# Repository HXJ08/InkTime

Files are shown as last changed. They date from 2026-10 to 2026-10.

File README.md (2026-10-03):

# InkTime

A 7.3" four-colour e-ink photo frame that shows a "today in history" photo every
morning. An ESP32-S3 wakes on a timer, pulls a pre-rendered 480x800 `.bin` frame
off a small HTTP host, paints it on a GDEM075F52 panel, overlays the live battery
level, and goes back to deep sleep.

The photos come from a self-hosted Immich library. A scoring pass picks the
photos that are actually worth showing, and a renderer composites the things you
actually want to see printed next to them: camera model, lens, exposure settings,
date and location.

```
Immich  ──►  analyze_photos.py  ──►  photos.db  ──►  render_daily_photo.py
(server)      VLM scoring pass       (SQLite)         compositing + dithering
                                                             │
                                                    photo_0..N.bin + previews
                                                             │
                                                             ▼
                                                 HTTP host ──► ESP32-S3 frame
```

## Gallery

**PCB** — ESP32-S3-InkDisplay v1.0, 100×33 mm, 2-layer. Red = top copper, blue = bottom, purple = vias.

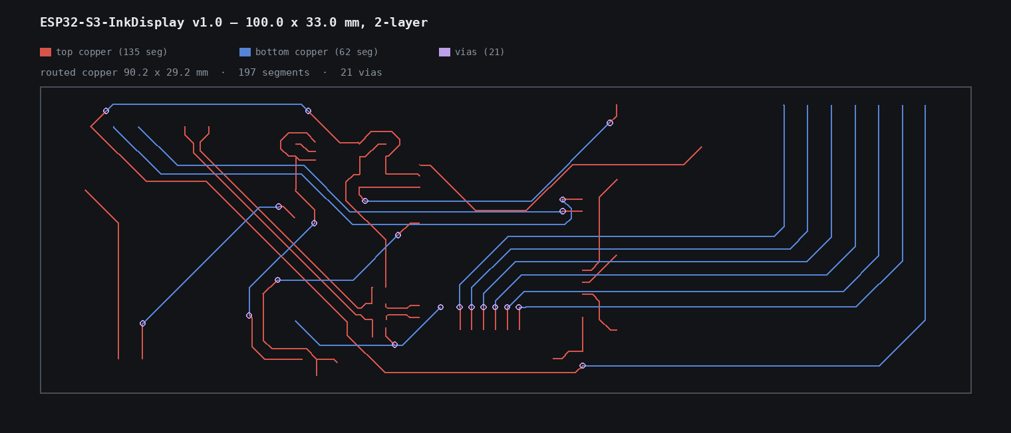
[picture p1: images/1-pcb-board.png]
PCB layout


**Rendered frame** — 480×800, 4-colour e-ink. Photo on top, specs + battery icon + date/location below.

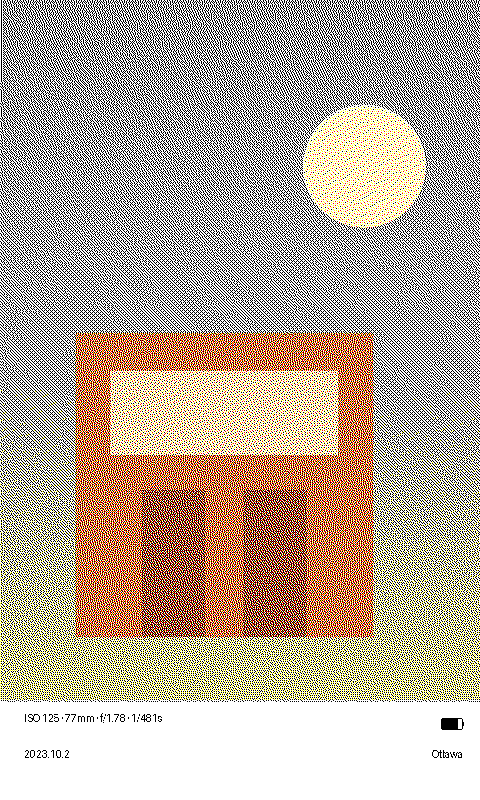
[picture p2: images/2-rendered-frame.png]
Rendered e-ink frame


**Repo** — 17 files, 5 commits on `main`.

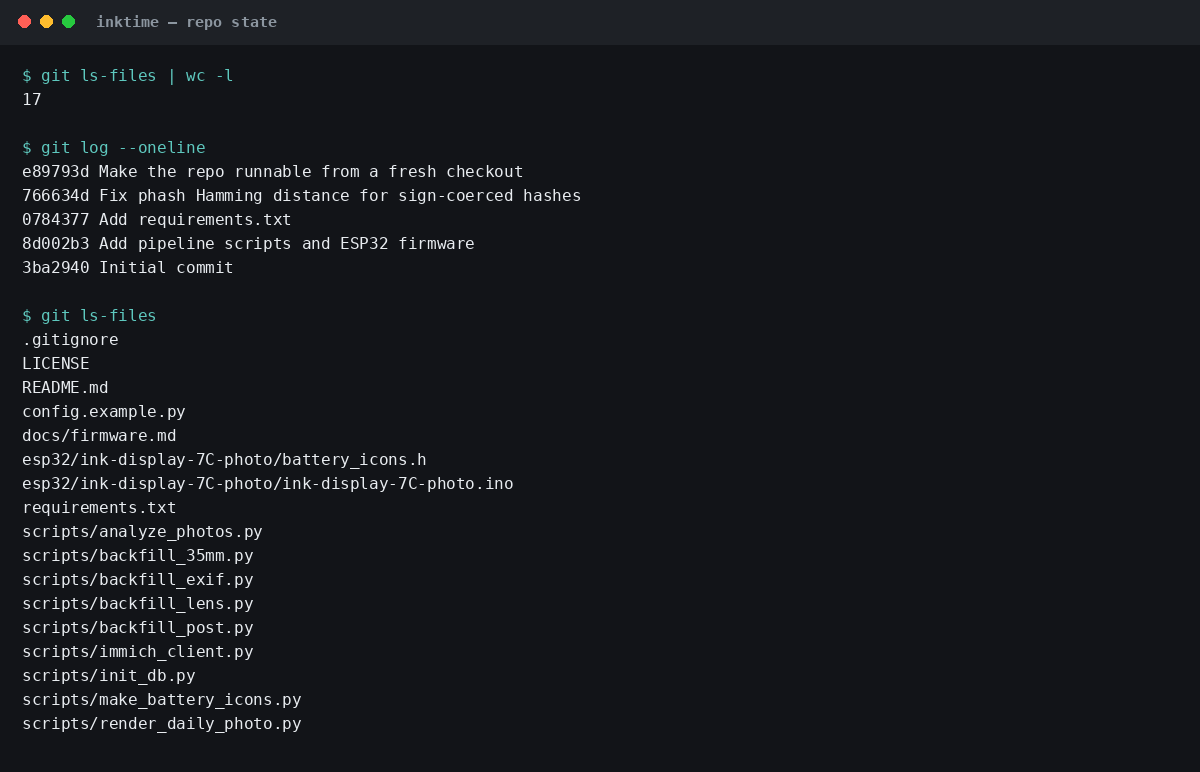
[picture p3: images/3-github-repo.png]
GitHub repo


## What is here

| Path | Role |
|---|---|
| `scripts/analyze_photos.py` | Pulls assets from Immich, scores them with a vision model, extracts EXIF, writes `photos.db` |
| `scripts/immich_client.py` | Immich REST client (ping, asset info, thumbnails, cache sync) |
| `scripts/render_daily_photo.py` | Selects today's photos, composites the info panel, dithers to 4 colours, writes `.bin` + previews |
| `scripts/init_db.py` | Creates a fresh `photos.db` with the full schema |
| `scripts/make_battery_icons.py` | Regenerates `battery_icons.h` (11 icons, 0-100%) |
| `scripts/backfill_*.py` | One-off repair passes over an existing database |
| `esp32/ink-display-7C-photo/` | Device firmware. Captive-portal Wi-Fi setup, download, battery overlay, deep sleep |
| `config.example.py` | Template for the untracked `config.py`; copy it to the repo root and edit |
| `docs/firmware.md` | Pinout, battery divider, `arduino-cli` build flags, calibration procedure |
| `hardware/` | PCB source (`.epro2`) and `bom.csv` — see `hardware/README.md` |

## The frame

`esp32/ink-display-7C-photo/` is one sketch plus one generated header.

- Panel: GDEM075F52, 480x800, four colours (black / white / red / yellow).
- Board: ESP32-S3 N8R8 (8 MB OPI PSRAM, 16 MB flash).
- `battery_icons.h` holds eleven 24x24 icons, 1 byte per pixel, palette `0=black 1=white 2=red 3=yellow`.
  Index 1 is transparent: the firmware paints white underneath and skips it.
- Battery is read on a 1S LiPo through a 100k/100k divider into an ADC pin, with a
  calibration factor and an 11-step voltage table in the sketch.
- `DAILY_PHOTO_PATH_PREFIX` in the sketch **must match** the renderer's output
  directory on the server. It ships as `CHANGEME_32_HEX_DOWNLOAD_KEY`; change it
  before flashing, otherwise the URL your frame requests is guessable by anyone
  who can reach the host.

Build flags matter. `build.psram=opi` is not optional: without it the framebuffer
allocation fails and init spins. Full command and the calibration walkthrough are
in `docs/firmware.md`.

## Server setup

Requires Python 3.10+, `Pillow`, `pillow-heif`, `requests`, and `exiftool` on
`PATH` (used for GPS/EXIF on originals; the pipeline degrades gracefully without it).

```sh
python -m venv venv && . venv/bin/activate
pip install -r requirements.txt
cp config.example.py config.py   # then edit it
```

`config.py` is read by every script and is **not** tracked. `config.example.py`
documents every key; the ones you cannot skip:

- `IMMICH_URL`, `IMMICH_API_KEY` - your Immich server. The key needs
  `asset.read`, `asset.view`, `asset.download` and `asset.update`.
  `asset.view` is a separate scope; without it thumbnails 403 even for the owner.
- `DB_PATH` - SQLite file. Everything else hangs off it.
- `BIN_OUTPUT_DIR` - where `.bin` frames land. Serve this over HTTP at the path
  prefix compiled into the firmware.
- `API_CHANNELS` - vision-model endpoints. Each entry is
  `{"api_url": ..., "model": ..., "api_key": "env:VAR_NAME"}`. Listing more than
  one makes the pass fail over on 429 instead of stalling.
- `WORLD_CITIES_CSV` - a GeoNames-style CSV with `lat,lon,name_en,name_zh`
  columns, used for reverse geocoding. Not shipped: it is a few MB of upstream
  data. Without it the location line renders empty rather than wrong.

Then:

```sh
python scripts/init_db.py                 # once: create the database schema
python scripts/analyze_photos.py -j 1     # score + ingest. -j 1: SQLite deadlocks higher
python scripts/render_daily_photo.py      # today's frames -> BIN_OUTPUT_DIR
```

Both are designed to run from cron or a container scheduler. The analyzer is
idempotent per asset; the renderer marks what it used so the next run picks
different photos.

## Database

One SQLite file, one main table. `photo_scores` is keyed on `path`, with
`immich_asset_id` as the join key back to Immich, plus the EXIF columns the
renderer reads (`exif_datetime`, `exif_make`, `exif_model`, `exif_iso`,
`exif_exposure_time`, `exif_f_number`, `exif_focal_length`, `exif_lens`,
`exif_focal_35mm`, `exif_file_size`, `exif_gps_*`, `exif_city`), the scoring
columns (`memory_score`, `beauty_score`, `reason`), and bookkeeping (`phash`,
`used_at`, `people_json`).

Two notes for anyone adapting this:

- `ensure_table()` creates `photo_scores` and `face_allowlist`, and adds columns
  individually for forward migration. `photo_blacklist` and the newer EXIF
  columns (`exif_focal_35mm`, `exif_lens`, `exif_file_size`, `album`) were added
  by the backfill scripts on the original deployment and are not created by
  `ensure_table()` — so run `scripts/init_db.py` once against a fresh database
  (it is idempotent) or the renderer's LEFT JOIN fails on first run.
- `phash` is stored as an integer in a signed column. Perceptual hashes use the
  full 64-bit range and are compared with Hamming distance after masking; if you
  rewrite the dedupe path, keep the masking.

## Selection

A photo is eligible when it has a parseable EXIF blob, scores above
`MEMORY_THRESHOLD`, is not blacklisted, and was not used inside
`USED_COOLDOWN_DAYS`. Among the eligible set the renderer prefers the same
calendar day in past years; if nothing clears the bar it walks back a day at a
time, and finally falls back to the global maximum. `DAILY_PHOTO_QUANTITY`
frames are written per run and the frame picks one at random, so a day's frame is
not predictable from the last one.

Deduplication runs before scoring, not after: an 8x8 difference hash with a
strict distance for near-identical frames, plus a wider distance inside a short
time window to catch bursts. It costs a model call to score a photo, so throwing
out the near-duplicates first is the cheap order.

## Attribution

The 4-colour dithering and the info-panel layout follow the conventions of
Apple Photos' detail panel (camera, lens, exposure, date, place). Focal length is
shown as the **35mm equivalent**, read from EXIF tag `0xA405`, because that is the
number people recognise; the physical value is meaningless for phone photos.
Previews render a copy of the battery icon so the PNG matches the frame; the
`.bin` deliberately does not contain it, because the frame draws the live level.

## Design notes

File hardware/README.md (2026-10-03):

# Hardware

PCB source and bill of materials for the InkTime frame.

| File | What it is |
|---|---|
| `ESP32-S3-InkDisplay-v1.0.epro2` | EasyEDA Pro project (opens in EasyEDA Pro) |
| `project2.json` | Project manifest, extracted from the `.epro2` |
| `bom.csv` | Bill of materials, exported from EasyEDA — 17 line items, 24 components |

## Board

**ESP32-S3-InkDisplay v1.0** — 100.0 × 33.0 mm, 2-layer.

Originally an open-source design by `Donald` (the silkscreen credits him);
modified by HXJ08. The `.epro2` dated 2026-10-02 is the modified revision.

**Power path:**

```
LiPo ──► TP4056 (charge) ──► VBAT ──► MIC5219-3.3 LDO ──► 3V3 ──► ESP32-S3
                                    └──► 100k/100k divider ──► ADC (battery sense)
```

**Display:** 8-pin SPI header (BUSY / CS / DC / RST / DIN / SCK / 3V3 / GND) to the
GDEM075F52 panel.

**USB:** D+/D− routed as a declared differential pair (DP1/DP2).

## BOM

Sourced from EasyEDA's own export (`BOM_V1_PCB1_2026-10-03.xlsx`), so the LCSC
supplier part numbers are included and the values are authoritative.

| Designators | Qty | Value | Manufacturer Part | LCSC |
|---|---|---|---|---|
| C1 | 1 | 4.7 µF | `CL10A475KO8NNNC` | C19666 |
| C2 | 1 | 10 µF | `CL10A106KP8NNNC` | C19702 |
| C3 | 1 | 100 nF | `CL10B104KB8NNNC` | C1591 |
| C4 | 1 | 1 µF | `CL10A105KB8NNNC` | C15849 |
| C5, C6 | 2 | 47 pF | `CL10C470JB8NNNC` | C1671 |
| C7 | 1 | 100 nF | — | — |
| R1, R4 | 2 | 10 kΩ | `RC1608F103CS` | C17441167 |
| R2, R3 | 2 | 22 Ω | `0603WAF220JT5E` | C23345 |
| R5, R6 | 2 | 100 kΩ | — | — |
| SW1-SW4 | 4 | — | `KH-6X6X5H-STM` | C2837531 |
| H1 | 1 | — | `PZ254V-11-04P` | C2691448 |
| H2 | 1 | — | `PZ254V-11-02P` | C492401 |
| H3 | 1 | — | `PZ254V-11-01P` | C492400 |
| H4 | 1 | — | `HC-PZ254-11.5L-1x8PZ` | C27985192 |
| U1 | 1 | — | `ESP32-S3-WROOM-1-N8R8` | C2913201 |
| U2 | 1 | — | `MIC5219-3.3YM5-TR` | C29613 |
| U3 | 1 | — | `TP4056` | — |

**24 components total.** C7, R5/R6 and U3 have values but no supplier part number
recorded — they are generic and need picking at order time.

## Notes before ordering

- **Two footprints are marked `DNI`** on the silkscreen. If they are deliberate, the
  assembler must be told to skip them.
- **No DRC result is stored in the project file.** The design rules are present
  (0.127 mm min track, 0.15 mm gap, 0.30 mm board-edge clearance) but a clean pass is
  not asserted — re-run DRC in EasyEDA first.
- **`bom.csv` is EasyEDA's export, not a derivation.** An earlier version of this file
  was reconstructed by parsing the PCB geometry and got three parts wrong: C2 as 4.7 µF
  instead of 10 µF, C7 as blank instead of 100 nF, and R5/R6 as 10 kΩ instead of 100 kΩ.
  The schematic knows values the PCB file does not, which is why the export supersedes it.

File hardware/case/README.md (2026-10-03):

# Case

3D-printed enclosure for the InkTime frame.

| File | What it is |
|---|---|
| `Inktime.stl` | Mesh export, ready to slice |
| `Inktime.f3d` | Autodesk Fusion 360 source document |
| `case_features.png` | Rendered features sheet (iso, cutaway, two sections) |

## Dimensions

**152.5 × 202.5 × 17.0 mm.** The tall dimension is the panel length: a 7.3"
display is 163 mm on the diagonal, so the case carries it with a margin for the
bezel lip.

**2,838 triangles, watertight** (0 open boundary edges), enclosing **131.9 cm³**
of material. Roughly 165 g of PLA at 1.24 g/cm³ before slicing adds walls and infill.

## Structure

The part is an **open tray**, not a closed box:

- **3 mm base** at z ≈ 3, with the outer floor at z ≈ 0.2
- **End walls** rising to z ≈ 10.4
- **Internal ribs and bosses** along the length, at a repeating pitch — visible in
  the X-section, these are the standoffs that hold the PCB and stop the base flexing
- **Bezel lip** at z = 14.2 → 17.2, the raised rim that frames the panel
- Two small slots in the top face near the midpoint

Height bands in the model: 3.2 mm (base top), 6.0 mm, 10.4 mm (wall top),
13.2 mm, 14.2 mm (bezel start), 17.2 mm (bezel top).

## Source

The Fusion document carries a `Toolpath` asset, so there is a CAM setup saved
alongside the model. `Inktime.f3d` is the authoritative source — edit that and
re-export the STL rather than editing the mesh.

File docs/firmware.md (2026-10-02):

# InkTime 7C-photo 固件构建

适用于 **ESP32-S3 N8R8 + GDEM075F52 (480x800 4 色屏)** 墨水相框。

## 引脚对照

| 信号 | GPIO | 备注 |
|---|---|---|
| EPD BUSY | 9 |  |
| EPD RST  | 12 |  |
| EPD DC | 11 |  |
| EPD CS | 10 |  |
| EPD SCK  | 14 |  |
| EPD MOSI | 13 |  |
| BAT ADC  | 6  | 1S LiPo + 100k+100k 1:2 分压 |
| FACTORY RESET | 38 | 上电低电平触发 |
| LED | 2 | LED_BUILTIN |

## 电池分压电路

```
B+ ──┬── 100k ──┬── GPIO6
B- ──┘          │
                ├── 100k ── GND
                │
ESP32 GND ──────┘
```

## arduino-cli 构建命令

```bash
arduino-cli compile \
  --fqbn esp32:esp32:esp32s3 \
  --build-property "build.psram=opi" \
  --build-property "build.flash_size=16MB" \
  --build-property "build.partitions=min_spiffs" \
  --build-property "build.board=ESP32-S3-DevKitC-1" \
  --build-property "build.variant=esp32s3" \
  -u \
  esp32/ink-display-7C-photo
```

> ⚠️ `build.psram=opi` 必填，否则 framebuffer 分配失败 / init 死循环。
> ⚠️ N8R8 = 8MB OPI PSRAM，必须显式声明。
> ⚠️ `min_spiffs` 选这个分区方案以腾出更多 app 空间。

## GxEPD2 库

库版本 ≥ 1.5.x（需要 `GxEPD2_750c_GDEM075F52` 驱动 + `GxEPD2_4C` 模板）。

Arduino IDE 库管理器搜 "GxEPD2" 装最新即可。

## 画面布局（Apple Photos 风格信息面板）

渲染器（`render_daily_photo.py`）在照片底部 140px 区域画 5 行信息：

```
[相机型号(粗体)]                    [电池图标(ESP32 叠加)]
[镜头名称]
[分辨率 · 文件大小]
[ISO · 焦距 · 光圈 · 快门]
[日期]                    [地点]
```

- 电池图标位置：`battery_icons.h` 里 `BATTERY_ICON_X/Y`（440, 676），
  ESP32 在下载 .bin 后把它叠加到 framebuffer，渲染器留出该区域。
- 文字区高度 `TEXT_AREA_HEIGHT = 140`（y=660..800），渲染器与固件必须保持同步。

## 电池阈值（LiPo 9060100 8000mAh 1S）

| 等级 | 电池端 mV | 备注 |
|---|---|---|
| 100% | ≥ 4125 | 4.125V |
| 90%  | ≥ 3950 | 3.95V |
| 80%  | ≥ 3850 | 3.85V |
| 70%  | ≥ 3780 | 3.78V |
| 60%  | ≥ 3720 | 3.72V |
| 50%  | ≥ 3660 | 3.66V |
| 40%  | ≥ 3600 | 3.60V |
| 30%  | ≥ 3550 | 3.55V |
| 20%  | ≥ 3450 | 3.45V |
| 10%  | ≥ 3300 | 3.30V |
| 0% | < 3300 | 3.00V 以下视为关机电压（代码里 3000mV 为下限） |

可在 `ink-display-7C-photo.ino` 顶部 `BATTERY_LEVEL_MV[]` 数组里按实际带载标定。

### 校准（解决 ADC 误差）

ADC eFuse 校准 + 电阻公差会让读出的电压有几 % 偏差。校准步骤：

1. 烧当前固件，串口 log 里看 `[BAT] adcMv=XXXX batMv=YYYY`（YYYY 是当前算出的电池电压）
2. 万用表量电池两端电压 V_actual
3. 算 `factor = V_actual / YYYY`
4. 改 `BATTERY_CALIBRATION_FACTOR` 常量，重刷

例：万用表 4.126V，串口 log 显示 `batMv=4050` → `factor = 4.126 / 4.050 = 1.019` → 改成 `1.019f`。

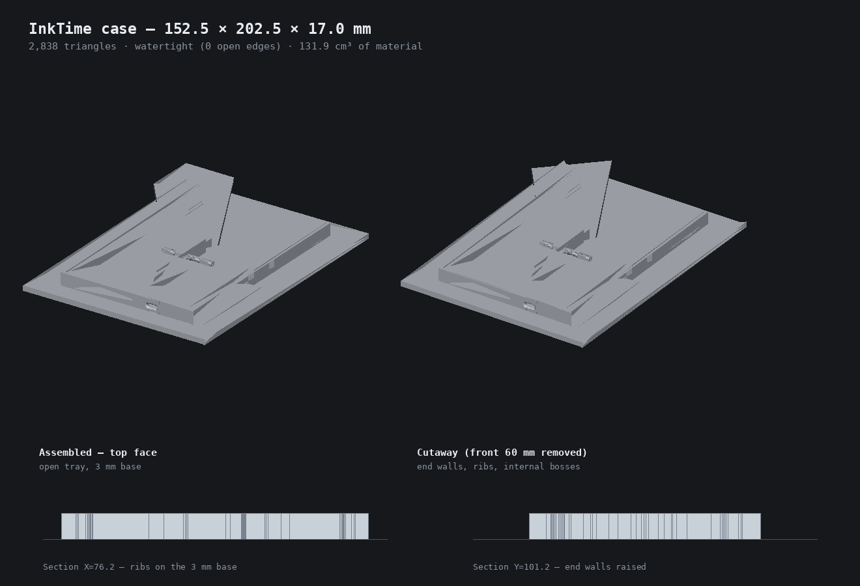
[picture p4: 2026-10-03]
hardware/case/case_features.png

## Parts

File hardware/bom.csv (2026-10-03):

Designator | Quantity | Value | Manufacturer Part | Manufacturer | Supplier Part | Supplier | Footprint
C1 | 1 | 4.7uF | CL10A475KO8NNNC | SAMSUNG(三星) | C19666 | LCSC | C0603
C2 | 1 | 10uF | CL10A106KP8NNNC | SAMSUNG(三星) | C19702 | LCSC | C0603
C3 | 1 | 100nF | CL10B104KB8NNNC | SAMSUNG(三星) | C1591 | LCSC | C0603
C4 | 1 | 1uF | CL10A105KB8NNNC | SAMSUNG(三星) | C15849 | LCSC | C0603
C5,C6 | 2 | 47pF | CL10C470JB8NNNC | SAMSUNG(三星) | C1671 | LCSC | C0603
C7 | 1 | 100nF |  |  |  |  | C0603
H1 | 1 | PZ254V-11-04P | PZ254V-11-04P | XFCN(兴飞) | C2691448 | LCSC | HDR-TH_4P-P2.54-V-M
H2 | 1 | PZ254V-11-02P | PZ254V-11-02P | XFCN(兴飞) | C492401 | LCSC | HDR-TH_2P-P2.54-V-M
H3 | 1 | PZ254V-11-01P | PZ254V-11-01P | XFCN(兴飞) | C492400 | LCSC | HDR-TH_1P-P2.54-V-M
H4 | 1 | HC-PZ254-11.5L-1x8PZ | HC-PZ254-11.5L-1x8PZ | HC(虹成电子) | C27985192 | LCSC | HDR-TH_8P-P2.54-V-M
R1,R4 | 2 | 10kΩ | RC1608F103CS | SAMSUNG(三星) | C17441167 | LCSC | R0603
R2,R3 | 2 | 22Ω | 0603WAF220JT5E | UNI-ROYAL(厚声) | C23345 | LCSC | R0603
R5,R6 | 2 | 100kΩ |  |  |  |  | R0603
SW1,SW2,SW3,SW4 | 4 | KH-6X6X5H-STM | KH-6X6X5H-STM | kinghelm(金航标) | C2837531 | LCSC | SW-SMD_4P-L6.0-W6.0-P4.50-LS9.0_H5.0
U1 | 1 | ESP32-S3-WROOM-1-N8R8 | ESP32-S3-WROOM-1-N8R8 | ESPRESSIF(乐鑫) | C2913201 | LCSC | WIRELM-SMD_ESP32-S3-WROOM-1
U2 | 1 | MIC5219-3.3YM5-TR | MIC5219-3.3YM5-TR | MICROCHIP(美国微芯) | C29613 | LCSC | SOT-23-5_L3.0-W1.7-P0.95-LS2.8-TL
U3 | 1 | TP4056 |  |  |  |  | PWRM-TH_TP4056

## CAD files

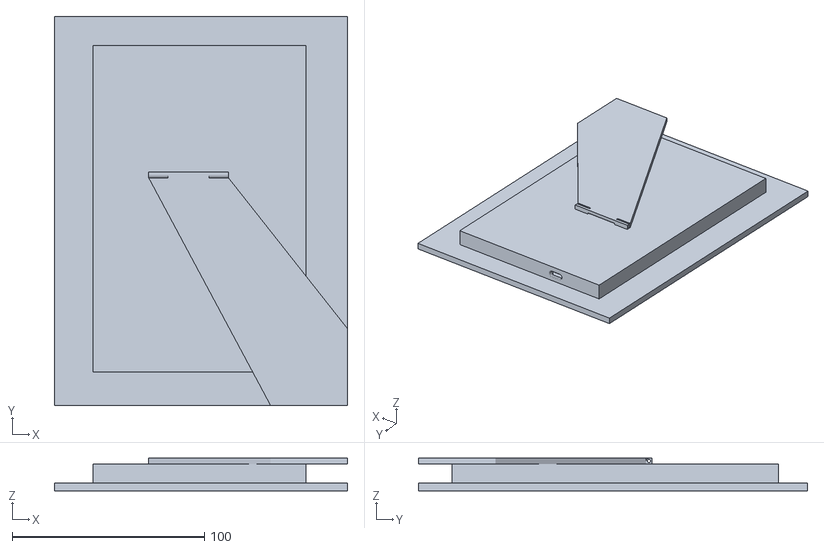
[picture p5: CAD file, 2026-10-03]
hardware/case/Inktime.stl
152.5 x 202.5 x 17.0

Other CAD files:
hardware/case/Inktime.f3d

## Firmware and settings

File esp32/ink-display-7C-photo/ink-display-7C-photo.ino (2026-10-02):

#include <WiFi.h>
#include <WebServer.h>
#include <HTTPClient.h>
#include <Preferences.h>
#include <SPI.h>
#include <time.h>
#include "esp_heap_caps.h"
#include "esp_system.h"
#include "esp_sleep.h"

#include <GxEPD2_4C.h>
#include <HardwareSerial.h>
#include "esp_wifi.h"
#include "esp_bt.h"

#include "driver/gpio.h"
#include "driver/rtc_io.h"

#include "battery_icons.h"

// =======================
//  调试开关（需要串口时改成 1）
// =======================
#define DEBUG_LOG 0

HardwareSerial DebugSerial(0);

#if DEBUG_LOG
  #define DBG_BEGIN()    DebugSerial.begin(115200)
  #define DBG_PRINT(x)   DebugSerial.print(x)
  #define DBG_PRINTLN(x) DebugSerial.println(x)
#else
  #define DBG_BEGIN()
  #define DBG_PRINT(x)
  #define DBG_PRINTLN(x)
#endif

#ifndef LED_BUILTIN
#define LED_BUILTIN 2
#endif

// =======================
//  恢复出厂设置：上电时按下 GPIO38 -> 清 NVS 中的 WiFi/配置，并进入 AP 配网
// =======================
#define PIN_FACTORY_RESET 38
#define FACTORY_RESET_ACTIVE_LOW 1
static const uint32_t FACTORY_RESET_SAMPLE_DELAY_MS = 5;

// =======================
//  AP 配置页保底：进入 AP 后 5 分钟没保存配置 -> 睡到“下一个刷新点”
// =======================
static const uint32_t AP_TIMEOUT_MS = 5UL * 60UL * 1000UL; // 5 分钟

// =======================
//  墨水屏参数 & 引脚
// =======================
// 逻辑分辨率：竖屏 480x800
static const int EPD_WIDTH  = 800;
static const int EPD_HEIGHT = 480;
static const int FB_WIDTH   = 480;
static const int FB_HEIGHT  = 800;

// SPI引脚 (重映射: BUSY=9, RST=12, DC=11, CS=10, SCK=14, MOSI=13)
#define PIN_EPD_BUSY 9
#define PIN_EPD_RST  12
#define PIN_EPD_DC   11
#define PIN_EPD_CS   10
#define PIN_EPD_SCLK 14
#define PIN_EPD_DIN  13

// =======================
//  电池电量检测 (1S LiPo 3.7V 8000mAh, 100k+100k 1:2 分压到 ADC)
// =======================
// 分压前电池电压: 4.20V (满) -> 3.00V (空)
// 分压后 ADC 端电压: 2.10V -> 1.50V
// ADC 引脚: GPIO6 (ADC1_CH5 on ESP32-S3, ADC2 在 WiFi 占用时不可用)
#define PIN_BATTERY_ADC   6
#define BATTERY_ADC_ATTEN ADC_11db          // ESP32-S3 上对应 0-3.3V 量程 (Arduino core 3.x 改名为 ADC_11db)
#define BATTERY_DIVIDER_RATIO 2.0f         // V_adc/V_bat = 100k/200k = 0.5 -> V_bat = V_adc * 2
#define BATTERY_ADC_SAMPLES 16

// 校准因子 — 补偿 ADC eFuse 误差 + 电阻公差
// 校准步骤:
//   1. 烧固件, 串口 log 看 [BAT] adcMv=XXXX (这是 ADC 引脚实测 mV, 已扣分压)
//   2. 用万用表实测电池两端 V_actual
//   3. factor = V_actual / (adcMv × 2.0)   ← 直接基于原始 adcMv 算, 不受上一次的 cal 影响
//   4. 改这个常量, 重刷
// 例: adcMv=2048, 万用表=4.126V → factor = 4.126 / (2048×2.0/1000) = 4.126 / 4.096 = 1.0073
#define BATTERY_CALIBRATION_FACTOR 1.0150f  // ← 改这个值校准

// LiPo 放电曲线 -> 11 段离散等级 (0,10,20,...,100)
// 阈值数组是分压前 (电池端) 电压 mV，从高到低排列
static const uint16_t BATTERY_LEVEL_MV[11] = {
  4125,  // 100% (>= 4.125V)
  3950,  //  90% (>= 3.95V)
  3850,  //  80% (>= 3.85V)
  3780,  //  70% (>= 3.78V)
  3720,  //  60% (>= 3.72V)
  3660,  //  50% (>= 3.66V)
  3600,  //  40% (>= 3.60V)
  3550,  //  30% (>= 3.55V)
  3450,  //  20% (>= 3.45V)
  3300,  //  10% (>= 3.30V)
  3000,  //   0% (<  3.30V; 3.00V 为截止/关机电压)
};
static const uint8_t  BATTERY_LEVEL_PCT[11] = { 100, 90, 80, 70, 60, 50, 40, 30, 20, 10, 0 };

// 屏幕: GDEM075F52 (480x800 4色 panel, GDEM 系列 50ms reset)
// 4 色 panel class + GDEM 驱动。如果换用其它屏幕，请自行修改此处
GxEPD2_4C<
  GxEPD2_750c_GDEM075F52,
  GxEPD2_750c_GDEM075F52::HEIGHT / 4
> display(
  GxEPD2_750c_GDEM075F52(
    PIN_EPD_CS,
    PIN_EPD_DC,
    PIN_EPD_RST,
    PIN_EPD_BUSY
  )
);

// =======================
//  静态每日相册 BIN 路径前缀，建议修改，防止隐私泄露。需同步修改 config.py 中的 DOWNLOAD_KEY。
// =======================
#define DAILY_PHOTO_PATH_PREFIX "/static/inktime/CHANGEME_32_HEX_DOWNLOAD_KEY/photo_"
#define DAILY_PHOTO_COUNT       10   // 0..9

// =======================
//  配置存储 / WiFi / WebServer
// =======================
Preferences prefs;
WebServer  server(80);

struct Config {
  String  wifi_ssid;
  String  wifi_pass;
  String  backend_hostport;
  int32_t tz_offset_hours;   // legacy: 静态时区偏移,只在 tz_label 为空时使用
  String  tz_label;          // 选自 TZ_TABLE[i].label,带 DST 规则
  uint8_t refresh_hour;
  bool    rotate180;
  bool    valid;
};

const char*  DEFAULT_HOSTPORT = "";
const int32_t DEFAULT_TZ      = 8;
const uint8_t DEFAULT_HOUR    = 8;

Config g_cfg;
uint8_t* framebuffer = nullptr;

// =======================
//  时区表 (北美优先,含 DST 规则)
//  偏移量:东正西负,以秒计(与 configTime 的 gmtOffset_sec 同向)
//  DST 规则:美加 2007 年后统一(3 月第 2 个周日 -> 11 月第 1 个周日)
//  没有 DST 的地区 hasDst=false, dstOffsetSec 等于 stdOffsetSec
// =======================
struct TzInfo {
  const char* iana;           // IANA 时区名(用于 IP 检测匹配)
  const char* label;          // 下拉框里显示的完整标签(也是 NVS 里存的 key)
  int         stdOffsetSec;   // 标准时间偏移 (UTC+0 为 0)
  int         dstOffsetSec;   // 夏令时偏移
  bool        hasDst;         // 是否观察 DST
  const char* posix;          // POSIX TZ 字符串(参考,运行时不用)
};
static const TzInfo TZ_TABLE[] = {
  // 美东
  {"America/Halifax",     "America/Halifax (AST/ADT, PEI/NS/NB)",   -14400, -10800, true,  "AST4ADT,M3.2.0,M11.1.0"},
  {"America/St_Johns",    "America/St_Johns (NST/NDT, NL)",         -12600,  -9000, true,  "NST3:30NDT,M3.2.0,M11.1.0"},
  {"America/New_York",    "America/New_York (EST/EDT)",             -18000, -14400, true,  "EST5EDT,M3.2.0,M11.1.0"},
  {"America/Toronto",     "America/Toronto (EST/EDT, ON)",          -18000, -14400, true,  "EST5EDT,M3.2.0,M11.1.0"},
  // 美中
  {"America/Chicago",     "America/Chicago (CST/CDT)",              -21600, -18000, true,  "CST6CDT,M3.2.0,M11.1.0"},
  {"America/Winnipeg",    "America/Winnipeg (CST/CDT, MB)",         -21600, -18000, true,  "CST6CDT,M3.2.0,M11.1.0"},
  // 美山
  {"America/Denver",      "America/Denver (MST/MDT)",               -25200, -21600, true,  "MST7MDT,M3.2.0,M11.1.0"},
  {"America/Phoenix",     "America/Phoenix (MST, no DST, AZ)",      -25200, -25200, false, "MST7"},
  // 美西
  {"America/Los_Angeles", "America/Los_Angeles (PST/PDT)",          -28800, -25200, true,  "PST8PDT,M3.2.0,M11.1.0"},
  {"America/Vancouver",   "America/Vancouver (PST/PDT, BC)",        -28800, -25200, true,  "PST8PDT,M3.2.0,M11.1.0"},
  // 北美其它
  {"America/Anchorage",   "America/Anchorage (AKST/AKDT)",          -32400, -28800, true,  "AKST9AKDT,M3.2.0,M11.1.0"},
  {"Pacific/Honolulu",    "Pacific/Honolulu (HST, no DST)",         -36000, -36000, false, "HST10"},
  // 兜底
  {"UTC",                 "UTC",                                         0,      0,  false, "UTC0"},
  {"Asia/Shanghai",       "Asia/Shanghai (CST, no DST, 中国)",       28800,  28800, false, "CST-8"},
};
static const size_t TZ_TABLE_LEN = sizeof(TZ_TABLE) / sizeof(TZ_TABLE[0]);

// 按 label 查 TzInfo(线性查表,只有十几条,够用)
static const TzInfo* lookupTz(const String &label) {
  if (label.isEmpty()) return nullptr;
  for (size_t i = 0; i < TZ_TABLE_LEN; ++i) {
    if (label.equals(TZ_TABLE[i].label)) return &TZ_TABLE[i];
  }
  return nullptr;
}

// 按 IANA 名查 TzInfo(用于 IP 检测回填)
static const TzInfo* lookupTzByIana(const String &iana) {
  if (iana.isEmpty()) return nullptr;
  for (size_t i = 0; i < TZ_TABLE_LEN; ++i) {
    if (iana.equals(TZ_TABLE[i].iana)) return &TZ_TABLE[i];
  }
  return nullptr;
}

// 北美 DST 判断:3 月第 2 个周日(含) -> 11 月第 1 个周日(不含)
// 精度到"天",2 AM 边界的 1 小时误差对每日 8 AM 唤醒画屏可忽略
static bool isNorthAmericaDST(time_t nowUtc) {
  if (nowUtc <= 0) return false;
  struct tm utc;
  gmtime_r(&nowUtc, &utc);
  int year = utc.tm_year + 1900;
  if (year < 2007) return false;  // 2007 年前规则不同,不考虑

  // 算 3 月第 2 个周日 和 11 月第 1 个 周日 的"年中第几天"
  auto dayOfYear = [](int y, int m, int d) {
    static const int cum[] = {0,31,59,90,120,151,181,212,243,273,304,334};
    int doy = cum[m-1] + d;
    if (m > 2 && ((y%4==0 && y%100!=0) || y%400==0)) doy++;
    return doy;
  };
  auto weekdayOn1st = [](int y, int m) {
    // Zeller-like: 求某月 1 日是星期几 (0=Sun..6=Sat)
    static const int t[] = {0,3,2,5,0,3,5,1,4,6,2,4};
    int yy = y - (m < 3);
    int w = (yy + yy/4 - yy/100 + yy/400 + t[m-1] + 1) % 7;
    return w;  // 0=Sun
  };
  int firstSunMar = (7 - weekdayOn1st(year, 3)) % 7 + 1;  // 1..7
  int firstSunNov = (7 - weekdayOn1st(year, 11)) % 7 + 1;
  int dstStart = dayOfYear(year, 3, firstSunMar + 7);  // 2nd Sunday of March
  int dstEnd   = dayOfYear(year, 11, firstSunNov);     // 1st Sunday of November

  int doy = dayOfYear(year, utc.tm_mon + 1, utc.tm_mday);
  return (doy >= dstStart) && (doy < dstEnd);
}

// 计算当前应使用的 UTC 偏移(秒,东正)
// 优先用 tz_label(DST 自动),否则用老字段 tz_offset_hours
static int computeUtcOffsetSec(const Config &cfg) {
  const TzInfo* tz = lookupTz(cfg.tz_label);
  if (tz) {
    if (!tz->hasDst) return tz->stdOffsetSec;
    time_t nowUtc = time(nullptr);
    return isNorthAmericaDST(nowUtc) ? tz->dstOffsetSec : tz->stdOffsetSec;
  }
  return (int)cfg.tz_offset_hours * 3600;
}

// 把当前时区应用到 lwIP/SNTP 层;setup() 早期 + 任何 getLocalTime 前都要调一次
static void applyTimezone(const Config &cfg) {
  int offsetSec = computeUtcOffsetSec(cfg);
  configTime(offsetSec, 0, "pool.ntp.org", "time.nist.gov", "ntp.aliyun.com");
#if DEBUG_LOG
  DBG_PRINT("[TIME] tz="); DBG_PRINT(cfg.tz_label.isEmpty() ? String("(legacy)") : cfg.tz_label);
  DBG_PRINT(" offsetSec="); DBG_PRINTLN(offsetSec);
#endif
}

static void releaseAllGpioHoldsAtBoot() {
  gpio_deep_sleep_hold_dis();
  for (int gpio = 0; gpio <= 48; ++gpio) {
    gpio_num_t gn = (gpio_num_t)gpio;
    if (!GPIO_IS_VALID_GPIO(gn)) continue;
    gpio_hold_dis(gn);
    if (rtc_gpio_is_valid_gpio(gn)) rtc_gpio_hold_dis(gn);
  }
}

static void clearConfigNVS() {
#if DEBUG_LOG
  DBG_PRINTLN("[NVS] clearConfigNVS()");
#endif
  prefs.begin("dashcfg", false);
  prefs.clear();
  prefs.end();
}

static bool isFactoryResetRequestedAtBoot() {
  pinMode(PIN_FACTORY_RESET, INPUT_PULLUP);
  delay(FACTORY_RESET_SAMPLE_DELAY_MS);
#if FACTORY_RESET_ACTIVE_LOW
  return (digitalRead(PIN_FACTORY_RESET) == LOW);
#else
  return (digitalRead(PIN_FACTORY_RESET) == HIGH);
#endif
}

static void saveLastTimeEpoch(time_t epoch) {
  prefs.begin("dashcfg", false);
  prefs.putULong("last_epoch", (uint32_t)epoch);
  prefs.end();
#if DEBUG_LOG
  DBG_PRINT("[TIME] save last_epoch="); DBG_PRINTLN((uint32_t)epoch);
#endif
}

static bool loadLastTimeEpoch(time_t &epochOut) {
  prefs.begin("dashcfg", true);
  uint32_t v = prefs.getULong("last_epoch", 0);
  prefs.end();
  if (v == 0) return false;
  epochOut = (time_t)v;
  return true;
}

static uint32_t minutesToNextRefreshFromLastEpoch(const Config &cfg) {
  time_t lastEpoch;
  if (!loadLastTimeEpoch(lastEpoch)) {
    return 1440;
  }

  struct tm t;
  localtime_r(&lastEpoch, &t);

  int curMinOfDay = t.tm_hour * 60 + t.tm_min;
  int targetMin   = (int)cfg.refresh_hour * 60;
  int deltaMin;

  if (curMinOfDay < targetMin) deltaMin = targetMin - curMinOfDay;
  else                         deltaMin = 24 * 60 - (curMinOfDay - targetMin);

  if (deltaMin < 1) deltaMin = 24 * 60;
  if (deltaMin > 1440) deltaMin = 1440;
  return (uint32_t)deltaMin;
}

// =======================
//  配置读写
// =======================
void loadConfig(Config &cfg) {
  prefs.begin("dashcfg", true); // read-only
  cfg.wifi_ssid        = prefs.getString("ssid", "");
  cfg.wifi_pass        = prefs.getString("pass", "");
  cfg.backend_hostport = prefs.getString("hostport", DEFAULT_HOSTPORT);
  cfg.tz_offset_hours  = prefs.getInt("tz", DEFAULT_TZ);
  cfg.tz_label         = prefs.getString("tz_label", "");
  cfg.refresh_hour     = (uint8_t)prefs.getUChar("hour", DEFAULT_HOUR);
  cfg.rotate180        = prefs.getBool("rot180", false);
  prefs.end();

  cfg.valid = (cfg.wifi_ssid.length() > 0);

#if DEBUG_LOG
  DBG_PRINTLN("---- loadConfig ----");
  DBG_PRINT("[CFG] ssid="); DBG_PRINTLN(cfg.wifi_ssid);
  DBG_PRINT("[CFG] hostport="); DBG_PRINTLN(cfg.backend_hostport);
  DBG_PRINT("[CFG] tz_offset_hours="); DBG_PRINTLN(cfg.tz_offset_hours);
  DBG_PRINT("[CFG] tz_label="); DBG_PRINTLN(cfg.tz_label);
  DBG_PRINT("[CFG] refresh_hour="); DBG_PRINTLN((int)cfg.refresh_hour);
  DBG_PRINT("[CFG] rotate180="); DBG_PRINTLN(cfg.rotate180 ? "true" : "false");
  DBG_PRINT("[CFG] valid="); DBG_PRINTLN(cfg.valid ? "true" : "false");
#endif
}

void saveConfig(const Config &cfg) {
  prefs.begin("dashcfg", false);
  prefs.putString("ssid", cfg.wifi_ssid);
  prefs.putString("pass", cfg.wifi_pass);
  prefs.putString("hostport", cfg.backend_hostport);
  prefs.putInt("tz", cfg.tz_offset_hours);
  prefs.putString("tz_label", cfg.tz_label);
  prefs.putUChar("hour", cfg.refresh_hour);
  prefs.putBool("rot180", cfg.rotate180);
  prefs.end();

#if DEBUG_LOG
  DBG_PRINTLN("[CFG] saved");
#endif
}

// =======================
//  HTML 工具
// =======================
String htmlEscape(const String &s) {
  String out;
  out.reserve(s.length());
  for (size_t i = 0; i < s.length(); ++i) {
    char c = s[i];
    if      (c == '&')  out += F("&amp;");
    else if (c == '<')  out += F("&lt;");
    else if (c == '>')  out += F("&gt;");
    else if (c == '"')  out += F("&quot;");
    else                out += c;
  }
  return out;
}

static void wifiHardResetForPortal() {
#if DEBUG_LOG
  DBG_PRINTLN("[WIFI] wifiHardResetForPortal()");
#endif
  WiFi.scanDelete();
  WiFi.disconnect(true, true);
  WiFi.mode(WIFI_OFF);
  delay(200);

  WiFi.mode(WIFI_AP_STA);

  WiFi.setSleep(false);
  esp_wifi_set_ps(WIFI_PS_NONE);

  WiFi.scanDelete();
  delay(50);
}

String buildConfigPage() {
  WiFi.scanDelete();
  delay(30);

  int n = WiFi.scanNetworks(/*async=*/false, /*hidden=*/true);

#if DEBUG_LOG
  DBG_PRINT("[CFG] scanNetworks n="); DBG_PRINTLN(n);
#endif

  String curSsid  = g_cfg.wifi_ssid;
  String host     = htmlEscape(g_cfg.backend_hostport);
  int32_t tz      = g_cfg.tz_offset_hours;
  if (tz < -12 || tz > 14) tz = DEFAULT_TZ;
  String curTzLbl = g_cfg.tz_label;
  uint8_t hour    = g_cfg.refresh_hour;
  if (hour > 23) hour = DEFAULT_HOUR;
  bool rot180     = g_cfg.rotate180;

  String html;
  html.reserve(8192);

  html += F("<!DOCTYPE html><html><head><meta charset='utf-8'>");
  html += F("<meta name='viewport' content='width=device-width,initial-scale=1'>");
  html += F("<title>InkTime 设置</title></head><body>");
  html += F("<h2>InkTime 设置</h2>");
  html += F("<form method='POST' action='/save'>");

  html += F("WiFi SSID:<br>");
  html += F("<select id='ssid_select' style='width: 288px;' onchange=\"document.getElementById('ssid_input').value=this.value;\">");
  html += F("<option value=''>（手动输入或选择）</option>");
  if (n > 0) {
    for (int i = 0; i < n; ++i) {
      String s = WiFi.SSID(i);
      if (s.length() == 0) continue;
      String esc = htmlEscape(s);
      html += F("<option value='");
      html += esc;
      html += F("'");
      if (s == curSsid) html += F(" selected");
      html += F(">");
      html += esc;
      html += F("</option>");
    }
  }
  html += F("</select><br>");
  html += F("<input id='ssid_input' name='ssid' style='width: 280px;' value='");
  html += htmlEscape(curSsid);
  html += F("'><br><br>");

  html += F("密码:<br><input name='pass' type='password' style='width: 280px;'><br><br>");

  html += F("服务器 (host:port):<br><input name='hostport' size='40' value='");
  html += host;
  html += F("'><br><br>");

  html += F("每日刷新时间（0-23 点整）：<br><select name='hour'>");
  for (int h = 0; h < 24; ++h) {
    html += "<option value='";
    html += String(h);
    html += "'";
    if (h == hour) html += " selected";
    html += ">";
    html += String(h);
    html += F(" 点</option>");
  }
  html += F("</select><br><br>");

  html += F("时区（含 DST 自动切换）:<br>");
  html += F("<select name='tz_label' id='tz_label' style='width: 360px;'>");
  html += F("<option value=''>(不选,用下方手动偏移量)</option>");
  for (size_t i = 0; i < TZ_TABLE_LEN; ++i) {
    String lbl = String(TZ_TABLE[i].label);
    String esc = htmlEscape(lbl);
    html += "<option value='";
    html += esc;
    html += "'";
    if (lbl == curTzLbl) html += F(" selected");
    html += ">";
    html += esc;
    html += F("</option>");
  }
  html += F("</select>");
  html += F(" <button type='button' onclick='detectTz()'>根据 IP 自动检测</button><br>");
  html += F("<span id='tz_status' style='color:#666;font-size:12px;'></span><br>");
  html += F("<script>");
  html += F("function detectTz(){");
  html += F("var s=document.getElementById('tz_status');");
  html += F("s.textContent='检测中…';");
  html += F("fetch('/detect-tz').then(function(r){return r.text();}).then(function(t){");
  html += F("if(t==='FAIL'||t===''){s.textContent='检测失败,请手动选';s.style.color='#c00';return;}");
  html += F("var sel=document.getElementById('tz_label');");
  html += F("var hit=false;");
  html += F("for(var i=0;i<sel.options.length;i++){");
  html += F("if(sel.options[i].value===t){sel.selectedIndex=i;hit=true;break;}");
  html += F("}");
  html += F("if(hit){s.textContent='已自动选择: '+t;s.style.color='#080';}");
  html += F("else{s.textContent='检测到 '+t+' 但不在列表,请手动选';s.style.color='#c00';}");
  html += F("});}");
  html += F("</script><br>");

  html += F("手动偏移量 (仅当上面未选时区时生效, UTC+?):<br>");
  html += F("<select name='tz'>");
  for (int t = -12; t <= 14; ++t) {
    html += "<option value='";
    html += String(t);
    html += "'";
    if (t == tz) html += " selected";
    html += ">";
    if (t >= 0) html += "+";
    html += String(t);
    html += F("</option>");
  }
  html += F("</select><br><br>");

  html += F("<label><input type='checkbox' name='rot180' value='1'");
  if (rot180) html += F(" checked");
  html += F("> 画面旋转 180°</label><br><br>");

  if (n <= 0) {
    html += F("<p style='color:#c00'>未扫描到 WiFi，可直接在上方输入框手动填写 SSID。</p>");
  }

  html += F("<input type='submit' value='保存并重启'>");
  html += F("</form></body></html>");

  return html;
}

// =======================
//  WebServer 处理
// =======================
void handleRoot() {
#if DEBUG_LOG
  DBG_PRINTLN("[HTTP] GET /");
#endif
  server.send(200, "text/html; charset=utf-8", buildConfigPage());
}

void handleSave() {
#if DEBUG_LOG
  DBG_PRINTLN("[HTTP] POST /save");
#endif
  String ssid     = server.arg("ssid");
  String pass     = server.arg("pass");
  String host     = server.arg("hostport");
  String hourStr  = server.arg("hour");
  String tzLabel  = server.arg("tz_label");
  String tzLegacy = server.arg("tz");            // 老字段,只在用户没选新时区时回退
  bool rot180Req  = (server.arg("rot180") == "1");

  ssid.trim();
  host.trim();
  tzLabel.trim();

  Config newCfg = g_cfg;

  if (ssid.length() > 0) newCfg.wifi_ssid = ssid;
  if (pass.length() > 0) newCfg.wifi_pass = pass;

  newCfg.backend_hostport = host;

  // tz_label 优先:必须在 TZ_TABLE 里才接受(防止用户瞎填)
  if (!tzLabel.isEmpty() && lookupTz(tzLabel) != nullptr) {
    newCfg.tz_label = tzLabel;
  } else {
    newCfg.tz_label = "";
  }
  // 保留老字段(向后兼容;若 tz_label 非空则运行时忽略)
  int32_t tz = tzLegacy.toInt();
  if (tz < -12) tz = -12;
  if (tz > 14)  tz = 14;
  newCfg.tz_offset_hours = tz;

  int hour = hourStr.toInt();
  if (hour < 0)  hour = 0;
  if (hour > 23) hour = 23;
  newCfg.refresh_hour = (uint8_t)hour;

  newCfg.rotate180 = rot180Req;
  newCfg.valid     = (newCfg.wifi_ssid.length() > 0);

  saveConfig(newCfg);

  server.send(
    200,
    "text/html; charset=utf-8",
    F("<html><body><h3>保存成功，设备即将重启...</h3></body></html>")
  );

  delay(800);
  ESP.restart();
}

// =======================
//  IP 地理检测: GET ip-api.com/json/ -> 解析 timezone 字段
//  返回匹配的 TzInfo label,失败返回空字符串
// =======================
static String fetchTzFromIP() {
  if (WiFi.status() != WL_CONNECTED) return "";

  HTTPClient http;
  http.begin("http://ip-api.com/json/?fields=status,timezone");
  // 超时 4s:别在配网页上卡太久
  http.setTimeout(4000);
  int code = http.GET();
  if (code != HTTP_CODE_OK) {
#if DEBUG_LOG
    DBG_PRINT("[TZ] ip-api code="); DBG_PRINTLN(code);
#endif
    http.end();
    return "";
  }
  String body = http.getString();
  http.end();

  // 简单字符串解析,避开拉一个 ArduinoJson 依赖
  // 期望响应: {"status":"success","timezone":"America/Halifax"}
  // status != success 时(内网 IP / 限流)也放弃
  if (body.indexOf("\"status\":\"success\"") < 0) {
#if DEBUG_LOG
    DBG_PRINT("[TZ] ip-api not success: "); DBG_PRINTLN(body);
#endif
    return "";
  }
  int tIdx = body.indexOf("\"timezone\":\"");
  if (tIdx < 0) return "";
  tIdx += 12;
  int tEnd = body.indexOf("\"", tIdx);
  if (tEnd < 0 || tEnd <= tIdx) return "";
  String iana = body.substring(tIdx, tEnd);
  iana.trim();

  const TzInfo* tz = lookupTzByIana(iana);
  if (!tz) {
#if DEBUG_LOG
    DBG_PRINT("[TZ] no table match for iana="); DBG_PRINTLN(iana);
#endif
    return "";
  }
#if DEBUG_LOG
  DBG_PRINT("[TZ] IP detected "); DBG_PRINT(iana);
  DBG_PRINT(" -> "); DBG_PRINTLN(tz->label);
#endif
  return String(tz->label);
}

void handleDetectTz() {
#if DEBUG_LOG
  DBG_PRINTLN("[HTTP] GET /detect-tz");
#endif
  String label = fetchTzFromIP();
  if (label.isEmpty()) {
    server.send(200, "text/plain; charset=utf-8", "FAIL");
    return;
  }
  server.send(200, "text/plain; charset=utf-8", label);
}

// =======================
//  Deep Sleep 前
// =======================
void prepareDeepSleepDomains() {
  esp_sleep_pd_config(ESP_PD_DOMAIN_RTC_PERIPH,    ESP_PD_OPTION_OFF);
#if SOC_PM_SUPPORT_RTC_SLOW_MEM_PD
  // 原 ESP32 (original) 才有这个 power domain, ESP32-S3 没有
  esp_sleep_pd_config(ESP_PD_DOMAIN_RTC_SLOW_MEM,  ESP_PD_OPTION_OFF);
#endif
#if SOC_PM_SUPPORT_RTC_FAST_MEM_PD
  // 同上, ESP32-S3 上 SOC_PM_SUPPORT_RTC_FAST_MEM_PD 未定义
  esp_sleep_pd_config(ESP_PD_DOMAIN_RTC_FAST_MEM,  ESP_PD_OPTION_OFF);
#endif
}

// =======================
//  关闭墨水屏相关引脚，提升续航表现
//
//  包含引脚:
//    - EPD 6 根 (BUSY/RST/DC/CS/SCK/MOSI)
//    - 电池 ADC (GPIO6):  100k+100k 分压网络常开, ESP32 ADC 输入缓冲在 sleep 时有几 µA 漏电
//    - 出厂复位 (GPIO38): boot 后设过 INPUT_PULLUP, sleep 时需放掉
// =======================
static void powerDownEPD() {
  const int epdPins[] = {
    PIN_EPD_BUSY, PIN_EPD_RST, PIN_EPD_DC, PIN_EPD_CS, PIN_EPD_SCLK, PIN_EPD_DIN,
    PIN_BATTERY_ADC,    // GPIO6
    PIN_FACTORY_RESET,  // GPIO38
  };
  for (size_t i = 0; i < sizeof(epdPins)/sizeof(epdPins[0]); ++i) {
    int p = epdPins[i];
    pinMode(p, INPUT);
    pinMode(p, INPUT_PULLDOWN);
  }
}
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
void loop() {
}

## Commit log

2026-10-02 Add pipeline scripts and ESP32 firmware
    - analyze_photos.py: Immich ingest, dedupe (dhash), VLM scoring, EXIF extraction
    - render_daily_photo.py: selection, info-panel compositing, 4-colour dithering
    - immich_client.py: Immich REST client with thumbnail cache sync
    - make_battery_icons.py + battery_icons.h: 11-step 24x24 icon set
    - backfill scripts: one-off EXIF/lens/35mm-focal/album repairs
    - esp32/ink-display-7C-photo: firmware (captive portal, download, battery overlay, deep sleep)
    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
2026-10-02 Make the repo runnable from a fresh checkout
    - init_db.py: creates the full schema (photo_scores with every collected
    column, photo_blacklist, face_allowlist) that was previously assembled
    across ensure_table() and the one-off backfills; without it the renderer
    fails on its first LEFT JOIN against photo_blacklist
    - render: replace the hardcoded album='Post' filter with ALBUM_FILTER
    (default empty), so a database without the backfill tag renders
    - scripts resolve config.py and relative paths against the repo root
    - config.example.py: move to repo root, document ALBUM_FILTER
    - README: setup order now init_db -> analyze -> render
2026-10-03 Add gallery images to README
    - PCB layout plot (from .epru geometry)
    - Rendered e-ink frame preview
    - Repo state screenshot
2026-10-03 Add hardware: PCB source and BOM
    - hardware/ESP32-S3-InkDisplay-v1.0.epro2: EasyEDA Pro project
    - hardware/bom.csv: 26 line items, per-designator
    - hardware/README.md: power path, BOM summary, ordering caveats
    BOM derived from the PCB file (the project ships no exported BOM).
    [bom.csv]
2026-10-03 Replace BOM with EasyEDA's own export
    The previous bom.csv was reconstructed from PCB geometry and got three parts
    wrong: C2 (4.7uF -> 10uF), C7 (blank -> 100nF), R5/R6 (10k -> 100k). The
    schematic carries values the PCB file does not.
    - hardware/bom.csv: from BOM_V1_PCB1_2026-10-03.xlsx, 17 line items, 24 parts
    - includes LCSC supplier part numbers
    - hardware/README.md: corrected BOM table and summary
    [bom.csv, doc_34456b803672_BOM_V1_PCB1_2026-10-03.xlsx]
2026-10-03 Rename BOM export to its original filename
    [BOM_V1_PCB1_2026-10-03.xlsx]
2026-10-03 Add 3D case: STL, Fusion source, features render
    - Inktime.stl: 152.5 x 202.5 x 17.0mm, 2838 tris, watertight, 131.9 cm3
    - Inktime.f3d: Fusion 360 source (carries a saved CAM toolpath asset)
    - case_features.png: iso, cutaway and two cross-sections
    - README: structure (3mm base, end walls/ribs, 14.2-17.2mm bezel lip)
    [Inktime.f3d, Inktime.stl]
